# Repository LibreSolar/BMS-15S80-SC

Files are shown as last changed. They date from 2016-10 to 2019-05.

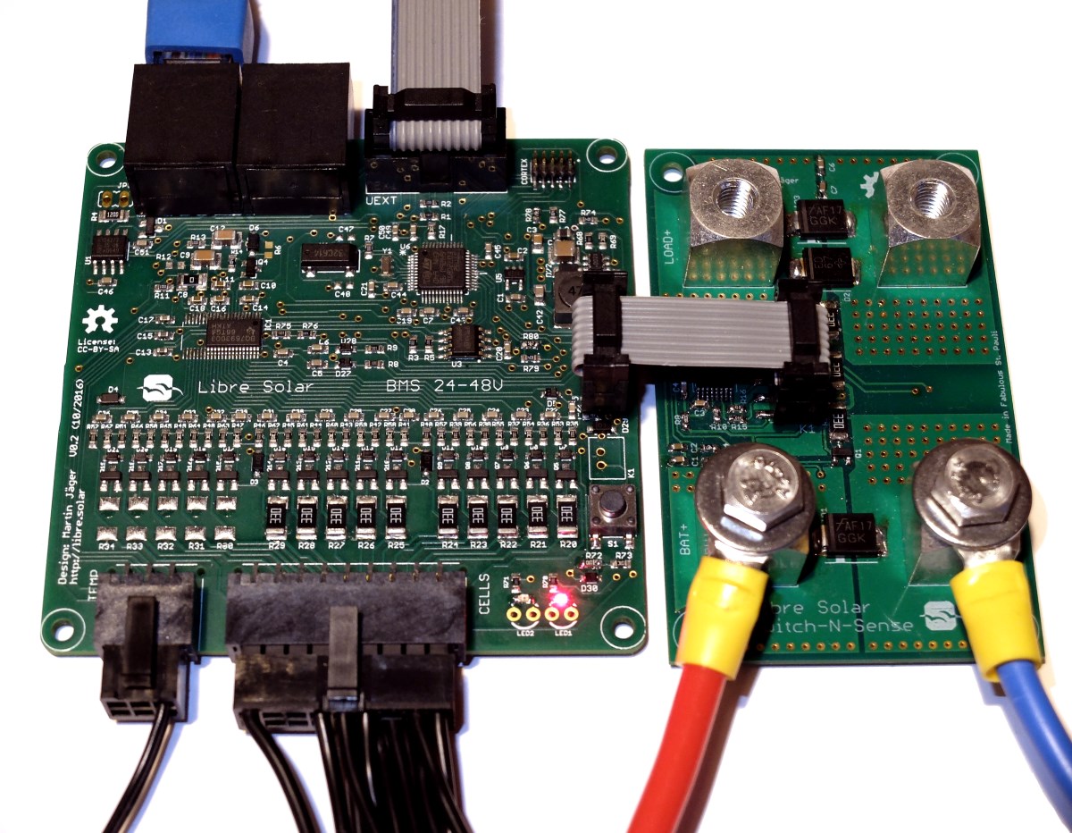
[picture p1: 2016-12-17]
doc/bms24v_board_20161217.jpg

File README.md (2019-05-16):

# BMS48V
Battery management system for up to 15 Li-ion cells based on bq76940 or bq76930 IC from Texas Instruments

Please find a good description about system integration of the BMS in the [Open Source Ecology Wiki](https://wiki.opensourceecology.de/24-48V_BMS) (in German).

## Features (updated version 10/2016):

- Up to 15 Li-ion cells (e.g. LiFePO4)
- Power circuit on separate board (see Switch-N-Sense repository)
- Balancing current approx. 150 mA
- STM32F072 ARM Cortex M0 microcontroller
- Built-in CAN communication interface and UEXT extension connector

## History

- Previous version was compatible to Arduino (based on ATmega 328P), but the processor was too small and didn't support CAN --> switched to STM32F072

(you can still find the old version by going back in the repository)

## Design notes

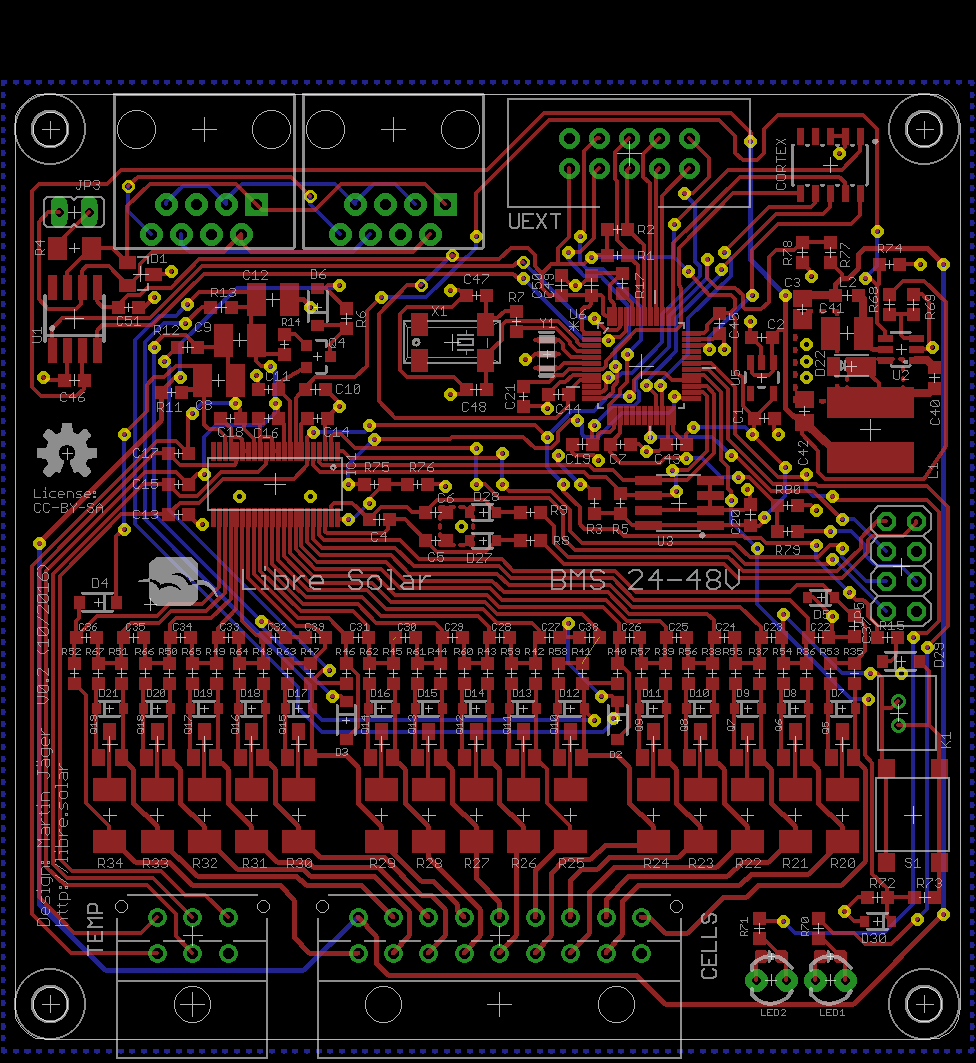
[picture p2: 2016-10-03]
LibreSolar_BMS48V_board.png

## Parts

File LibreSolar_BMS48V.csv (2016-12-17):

Qty | Value | Device | Package | Parts | Description | MF | MPN | OC_FARNELL | OC_NEWARK | PACKAGE | PROD_ID | SUPPLIER | VALUE
1 |  | 430182050816 | 430182050816 | S1 | 6x6 mm SMD WS-TASV
1 |  | 66201821022 | 66201821022 | CELLS | WR-MPC3 3.00mm Male Dual Row Angled Header with Plastic Pegs, 18 Pins=>Code : Con_WTB-MPC3_2_PCB_THT66201821022
1 |  | JP1Q | JP1 | JP3 | JUMPER
2 |  | LED0603 | LED-0603 | D24, D26 | LEDs |  |  | unknown
2 |  | LED3MM | LED3MM | LED1, LED2 | LEDs |  |  | unknown
1 |  | PINHD-2X4 | 2X04 | JP5 | PIN HEADER
1 | 0R | R-EU_R0603 | R0603 | R7 | RESISTOR, European symbol | YAGEO (PHYCOMP) | RC0603FR-0710KL | 9238603
3 | 100 | R-EU_R0603 | R0603 | R11, R12, R13 | RESISTOR, European symbol | MULTICOMP | MCMR06X1001FTL | 2073348
1 | 100k | R-EU_R0603 | R0603 | R14 | RESISTOR, European symbol |  |  | unknown
3 | 100k | R-EU_R0603 | R0603 | R72, R77, R79 | RESISTOR, European symbol | MULTICOMP | MCMR06X1001FTL | 2073348
1 | 100k | R-EU_R0603 | R0603 | R74 | RESISTOR, European symbol | PANASONIC ELECTRONIC COMPONENTS | ERJ3EKF1002V | 2303192
2 | 100n | C-EUC0603 | C0603 | C46, C51 | CAPACITOR, European symbol | AVX | 06035C104KAT2A | 1301804
6 | 100n | C-EUC0603 | C0603 | C20, C21, C43, C44, C45, C49 | CAPACITOR, European symbol | MURATA | GRM188R71H104KA93D | 8820023
24 | 100n | C-EUC0603 | C0603 | C4, C5, C6, C7, C19, C22, C23, C24, C25, C26, C27, C28, C29, C30, C31, C32, C33, C34, C35, C36, C37, C38, C39, C40 | CAPACITOR, European symbol | WALSIN | 0603B104K500CT | 2496834
1 | 10k | R-EU_R0603 | R0603 | R73 | RESISTOR, European symbol | MULTICOMP | MCMR06X1001FTL | 2073348
16 | 10k | R-EU_R0603 | R0603 | R53, R54, R55, R56, R57, R58, R59, R60, R61, R62, R63, R64, R65, R66, R67, R69 | RESISTOR, European symbol | PANASONIC ELECTRONIC COMPONENTS | ERJ3EKF1002V | 2303192
1 | 10k | R-EU_R0603 | R0603 | R17 | RESISTOR, European symbol | YAGEO (PHYCOMP) | RC0603FR-0710KL | 9238603
3 | 10µ | C-EUC1210 | C1210 | C8, C9, C12 | CAPACITOR, European symbol | MURATA | GRM32ER7YA106KA12L | 1735537
2 | 12.5p | C-EUC0603 | C0603 | C47, C48 | CAPACITOR, European symbol | MURATA | GRM188R71H104KA93D | 8820023
1 | 120 | R-EU_R1206 | R1206 | R4 | RESISTOR, European symbol | WELWYN | WCR0805-120RFI | 1100308
1 | 1M | R-EU_R0603 | R0603 | R76 | RESISTOR, European symbol | PANASONIC ELECTRONIC COMPONENTS | ERJU06F1004V | 2145441
5 | 1N4148W | DIODESOD123 | SOD-123 | D2, D3, D4, D6, D29 | Diode | DIODES INC. | 1N4148W-7-F. | 1776392
21 | 1k | R-EU_R0603 | R0603 | R8, R9, R35, R36, R37, R38, R39, R40, R41, R42, R43, R44, R45, R46, R47, R48, R49, R50, R51, R52, R75 | RESISTOR, European symbol | MULTICOMP | MCMR06X1001FTL | 2073348
1 | 1µ | C-EUC0603 | C0603 | C10 | CAPACITOR, European symbol | AVX | 0805YC475KAT2A | 1657937
1 | 1µ | C-EUC0603 | C0603 | C2 | CAPACITOR, European symbol | AVX | 08055C104KAT2A | 499687
4 | 1µ | C-EUC0603 | C0603 | C11, C14, C16, C18 | CAPACITOR, European symbol | MURATA | GRM188R71E105KA12D | 1735540
1 | 1µ | C-EUC0805 | C0805 | C3 | CAPACITOR, European symbol | AVX | 08055C104KAT2A | 499687
4 | 2.2k | R-EU_R0603 | R0603 | R1, R2, R3, R5 | RESISTOR, European symbol | YAGEO (PHYCOMP) | RC0603FR-072K2L. | 9238522
2 | 2.2µ | C-EUC0603 | C0603 | C1, C50 | CAPACITOR, European symbol | AVX | 0805YC475KAT2A | 1657937
1 | 2.2µ | C-EUC1210 | C1210 | C41 | CAPACITOR, European symbol | TDK | C3225X7R2A225K230AB | 2112727
1 | 22µ | C-EUC0805 | C0805 | C42 | CAPACITOR, European symbol | MURATA | GRM21BR60J226ME39L | 1735531
4 | 3.3V | DIODE-ZENER5.6V | SOD-323 | D5, D27, D28, D30 | Zener Diode | NXP | BZX384-C5V6 | 8735743 |  |  | DIO-12442 |  | 5.6V
15 | 33 | R-EU_R2010 | R2010 | R20, R21, R22, R23, R24, R25, R26, R27, R28, R29, R30, R31, R32, R33, R34 | RESISTOR, European symbol | WELWYN | ASC2010-33RFT4 | 2079038
2 | 330 | R-EU_R0603 | R0603 | R70, R71 | RESISTOR, European symbol | MULTICOMP | MCMR06X1001FTL | 2073348
3 | 4.7n | C-EUC0603 | C0603 | C13, C15, C17 | CAPACITOR, European symbol | WALSIN | 0603B104K500CT | 2496834
1 | 4.7uH | L-EUL2012C | L2012C | L2 | INDUCTOR, European symbol
1 | 47uH | WE-TPC_6823 | WE-TPC_6823 | L1 | Shielded Tiny Power Inductor WE-TPC
15 | 5.6V | DIODE-ZENER5.6V | SOD-323 | D7, D8, D9, D10, D11, D12, D13, D14, D15, D16, D17, D18, D19, D20, D21 | Zener Diode | NXP | BZX384-C5V6 | 8735743 |  |  | DIO-12442 |  | 5.6V
3 | 5.6k | R-EU_R0603 | R0603 | R15, R78, R80 | RESISTOR, European symbol | MULTICOMP | MCMR06X1001FTL | 2073348
1 | 56k | R-EU_R0603 | R0603 | R68 | RESISTOR, European symbol | BOURNS | CR0805-FX-1001ELF | 2008380
1 | 62000211622 | 62000211622 | 62000211622 | K1 | WR-WTB 2.00mm Male Vertical Shrouded Header, 2 Pins=>Code : Con_WTB_2.00_PCB_THT_62000211622
1 | 66200621022 | 66200621022 | 66200621022 | TEMP | WR-MPC3 3.00mm Male Dual Row Angled Header with Plastic Pegs, 6 Pins=>Code : Con_WTB-MPC3_2_PCB_THT66200621022
1 | 66200621122 | 66200621122 | 66200621122 | K4 | WR-MPC3 3.00mm Male Dual Row Vertical Header, 6 Pins=>Code : Con_WTB_MPC3_2_PCB_THT_66200621122
1 | 66201821122 | 66201821122 | 66201821122 | K5 | WR-MPC3 3.00mm Male Dual Row Vertical Header, 18 Pins=>Code : Con_WTB_MPC3_2_PCB_THT_66201821122
1 | 8MHz | RESONATOR1:1 | RESONATOR-SMD-1:1 | Y1 | Resonator | MURATA | CSTCE8M00G55-R0 | 2443270
1 | ABS25-32.768KHZ-T | CRYSTALMM20SS | MM20SS | X1 | CRYSTAL |  |  | unknown | unknown
1 | BQ76940 | BQ76940 | TSSOP44 | IC1 |  | TEXAS INSTRUMENTS | BQ7694003DBT | 2425791
1 | BSS123 | MOSFET-NCHANNELBSS138 | SOT23-3 | Q4 | Common NMOSFET Parts | NXP | 2N7002,215 | 1510761 |  |  | TRANS-00830 |  | 200mA/50V
1 | CORTEX_DEBUGSMD | CORTEX_DEBUGSMD | SAMTECH_FTSH-105-01 | CORTEX | Cortex Debug Connector
1 | DFLS1100-7 | SCHOTTKY-DIODEPOWERDI123 | POWERDI123 | D22 | Schottky Diode | DIODES INC. | DFLS1100-7 | 1713889
15 | DMN2004K | DMN2004K | SOT23 | Q5, Q6, Q7, Q8, Q9, Q10, Q11, Q12, Q13, Q14, Q15, Q16, Q17, Q18, Q19 | N-CHANNEL MOS FET with low VGS and ESD protection | DIODES INC. | DMN2004K-7 | 1713842
1 | LIBRESOLAR_LOGO | LIBRESOLAR_LOGO | LIBRESOLAR_LOGO | U$1
1 | LMR16006X | LMR16006SOT-23 | SOT23-6 | U2 | LMR16006 SIMPLE SWITCHER® 60 V 0.6 A Buck Regulators With High Efficiency ECO Mode | TEXAS INSTRUMENTS | LMR16006XDDCT | 2455133 |  |  |  |  | LMR16006
1 | M24256-BW | EEPROM-I2CSMD | SO08 | U3 | I2C EEPROM chips, 24LC256 (and others)
1 | MIC5225 | V_REG_MIC5235 | SOT23-5 | U5 |  | MICROCHIP | MIC5225-3.3YM5-TR | 2510262
4 | MOUNT-HOLE2.8 | MOUNT-HOLE2.8 | 2,8 | H1, H2, H3, H4 | MOUNTING HOLE with drill center marker |  |  | unknown
1 | OSHW-LOGOM | OSHW-LOGOM | OSHW-LOGO-M | N1 | Open Source Hardware Logo This logo indicates the piece of hardware it is found on incorporates a OSHW license and/or adheres to the definition of open source hardware found here: http://freedomdefined.org/OSHW |  |  | unknown
1 | PESD2CAN | PESD2CAN | SOT23 | D1 | CAN bus ESD protection diode | NXP | PESD2CAN | 1510712
2 | RJ45 | RJ45-8PTH | RJ45-8 | JP1, JP2 | RJ45 Jack | AMPHENOL COMMERCIAL PRODUCTS | RJHSE-5080 | 1860577 |  |  | CONN-08506 |  | RJ45
1 | STM32F072CB | STM32F072CB | QFP50P900X900X160-48N | U6 | ARM-based 32-bit MCU |  | STM32F100C4T6B | 1838504 | 86R1309 | LQFP-48 |  | STMircroelectronics
1 | TJA1042T/3 | TJA1042T/3 | SOIC-8-N | U1 | 3.3V CAN transceiver
1 | UEXT | UEXT | UEXT | UEXT | WR-BHD 2.54mm Male Box Header, 10 Pins=>Code : Con_WTB_BHD_2.54_Male_THT_WS_61201021621
1 | t.b.d. | R-EU_R0603 | R0603 | R6 | RESISTOR, European symbol | MULTICOMP | MCMR06X1001FTL | 2073348

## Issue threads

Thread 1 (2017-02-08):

More than 10 cells for 24V Batterypack

mulles, 2017-02-08:
Hi,

I am currently planning to build a 24V Batterypack with 16 Headway LifePO4 40152S 15Ah Cells. Which I would need 8 in Serie for 24V and would like to have 2x8Series in parallel for a 16Cell total. The goal is to power my room with 220Wp Solarpanel on 24Volt.

I like your project and I hope and some point you can ship the solarcharger and BMS to interested people.

My feature request would be to support more than 10cells, if that not the case yet, so that me and other can use the BMS in future.

Keep up the incredible work!

edit: I misunderstood some basics. I am all good with the 10 cells possibility :)

Closed 2017-02-08.

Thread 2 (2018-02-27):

CAN transceiver not working

martinjaeger, 2018-02-27:
The CAN_STB pin is not wired because of naming mismatch, so the CAN transceiver cannot be switched on. Workaround: Hard-wire it to GND.

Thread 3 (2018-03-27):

Specification

happytm, 2018-03-27:
What are the specifications for this board? specially compared to [http://electrodacus.com/SBMS100/manual/SBMSmanual.pdf](url)

martinjaeger, 2018-03-27:
Compared to the SBMS, this one has a more modular approach. The control PCB and the power PCB (Switch'N'Sense) are separated and it is not targeted only for solar applications. In addition to that, it can handle higher voltages and cell numbrrs.

happytm, 2018-03-27:
Thank you very much.

Closed 2018-03-27.

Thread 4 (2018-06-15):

Cell voltage measurement at group boundary influenced by balancing of adjacent cell

frankrichter, 2018-06-15:
The cell voltage measurements of cell 5 and 6 (also cell 10 and 11 with bq76940) are influenced by the balancing current of the adjacent cell in the other cell group.
The voltage deviation depends on the resistance between BMS and cell, in my case it was about 15-20mV. With this error the BMS can't achieve an accurate balancing.
This happens because the clocks of the 2 or 3 cell groups are not synchronized.

From "bq769x0 Family Top 10 Design Considerations" (SLUA749A) chapter 4 p. 9:
> The timelines of the cell groups in the bq76930 and bq76940 are independent, so one group may be balancing while the next group is measuring. At the cell boundary between groups, the adjacent cell may measure a voltage from the balance current in any common path. Keeping the common path resistance low, using wide traces or returning the current as close to the cell as possible will reduce this effect (see Figure 8).

Working solution/workaround: Remove the connections between VC5/VC5B and VC10/VC10B on the board and connect them to the respective cell with separate wires. Therefore the cells connector should be changed to a 20 pin model.
With 10s version it is possible to use one of the spare pins C11-C15 (see attached photos of my hacked board):
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

SolarDude, 2019-01-20:
frankrichter Nice catch!

So does your workaround as pictured also prevent this issue on Cell 10 & 11?

frankrichter, 2019-01-20:
No, if you use the 15 cell version, you also have to split the C10
connection. And you can't use any spare pins in this case either.

We are currently working on a pull request which adresses this issue by
replacing the cells connector with a 20 pin model.

Am So., 20. Jan. 2019, 05:12 hat SolarDude <notifications@github.com>
geschrieben:

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

SolarDude, 2019-01-20:
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

I want to make the changes on my board so the cell voltage is as accurate as possible.

The BQ76940 EVM is only using 16 cell input pins so are you saying that this issue voltage drop during balancing issue may be happening on the EVM module also? Or maybe not as noticeable because the EVM board is not setup with resistors to balance at 150mA which would cause a less of a voltage drop?

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

I think maybe the smaller traces running to the balancing resistors & circuit could also be adding to the voltage drop during balancing. You can see how wide the traces are that run to the balancing resistors on their EVM boards.

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

It seems like if we want to keep the board small and not increase the width of the traces running from the 18 or a new 20 pin connector to the balancing resistors then running a extra voltage sense wire to VC5B & VC10B pins would provide the most accurate cell voltage readings and balancing performance.

Took me awhile to wrap my head around what your workaround but now I understand what is going on.

I'm going to make these changes today. I've imported the Eagle project to KiCad 5.0.2-1 and that went well except for most of the Global Labels were just text so I have to change all those to proper Global Labels and the part text indicators needed moved around so they were not directly under some parts.

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

I'm adding the bq78350 chip to the mix the same as the EVM modules and I'm using the Particle Photon Wifi MCU since I'm used to using that module.

Do you see any reason this 48v board would not be usable with either the BQ76920, BQ76930, or BQ76940 AFE chips? It would be nice for one board to be able to handle 4, 8, 15 cell LiFePo4 battery Packs.

martinjaeger, 2019-01-20:
Very nice that you are transferring the board to KiCad. We could open a separate branch of the Particle Photon version or open a new repository, if you like.

Unfortunately, the bq76920 has a different pin pitch than the other two, so this this board currently supports only the 30 and 40 chips. I'm using it with the bq76930 and 8 cells.
The [TI top 10 design considerations document](http://www.ti.com/lit/an/slua749a/slua749a.pdf) makes a suggestion for board layout to support all 3 chip types. But it doesn't allow any traces below the chip anymore.

frankrichter, 2019-01-20:
> It seems like if we want to keep the board small and not increase the width of the traces running from the 18 or a new 20 pin connector to the balancing resistors then running a extra voltage sense wire to VC5B & VC10B pins would provide the most accurate cell voltage readings and balancing performance.

Yes, even with wider traces the measurements will still be affected by the voltage drop caused by the connector and the wire between BMS and cell.
Separate sense wires will do the trick regardless of the resistance and the applied balancing current. That's why I went for this solution.

SolarDude, 2019-01-20:
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

Makes sense.

The 20 pin connector can be added pretty easily without needing to move the current temp sensor port.

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

The new last 2 pins on the left of cell port just need to be connected to VC5B & VC10B to fix the issue.

I need to change all these global labels on the KiCad conversion before I can properly draw new wires to the new pins but the change is really easy. I'll report back once I get this done.

SolarDude, 2019-01-20:
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

I wonder if making a simple adapter board with castellated edges or something similar that would allow us to keep the current TSSOP 40 footprint but allow us to put the bq76920 chip on top of the adapter board and then reflow the adapter board to the 40 pin fooprint.

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

I'm not sure if this is possible, the pitch is really small.

SolarDude, 2019-01-20:
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

Your talking about cutting where you see the Blue X marks and adding where you see the bright RED lines?

Then connect the new C5+ & C10+ connections to where you see the White C5+ and C10+ text right?

frankrichter, 2019-01-20:
Your cuts are ok, your new connections aren't. You have to connect C5/C10 to the lower pad of R40/46, not to the upper pad.
Please refer to the photo in my first post. There is no connection between the enameled copper wire and the trace below.

frankrichter, 2019-01-20:
Yes, this is how we modded our board. Since then it is working flawlessly.

Additionnally it would make sense to connect the C5 and C10 vias to C5/C10 and not to the newly created C5+/C10+ like in your image, otherwise it won't work if you connect only 10 cells and leave out the C10+ connection which is not necessary for 10 cells.

SolarDude, 2019-01-20:
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

Great, makes sense to connect to the Vias as you did in your mod.

I think I know exactly what is going on now and can properly make the changes.

What is your battery pack setup? How much current? Which Sense board are you using?

SolarDude, 2019-01-20:
Looks like adding the footprint for the BQ76920 would not require to much modification based on what I'm seeing here:

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

I'm going attempt to add the footprint and make this a board that can handle the whole range of normal battery pack configurations.

frankrichter, 2019-01-20:
> Great, makes sense to connect to the Vias as you did in your mod.

In the mod the via is connected to C5+/C10+ like in your image. In a new layout this should be avoided.

> What is your battery pack setup?

9 of these cells: https://www.lithiumakkushop.de/product/innopower-lfmp-60ah/

> How much current?

about 30A

> Which Sense board are you using?

https://github.com/LibreSolar/Switch-N-Sense

SolarDude, 2019-01-21:
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

So just so we are clear.

You are saying the new C5+ and C10+ should connect at the vias that the orange arrows are pointing to?

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

SolarDude, 2019-01-21:
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

SolarDude, 2019-01-21:
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

What kind of heat does the sense board produce at 30 amps?

How much current testing have you done with the board? Just curious what is possible.

I have one on order with 2oz copper on both sizes of the board.

frankrichter, 2019-01-21:
I will do a quick drawing in the evening, but it's not as complicated as you think ;-)

SolarDude, 2019-01-21:
I think I got the new 20 Pin connector added and the wiring modified to prevent the cell voltage offset issue from happening. Take a look at the schematic and let me know if you see anything wrong.

I made sure I copied the new schematic you posted so we are on the same page as far as the C5 & C10 connections.

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

frankrichter, 2019-01-21:
Looks good!

photon-delight, 2020-11-11:
> Very nice that you are transferring the board to KiCad. We could open a separate branch of the Particle Photon version or open a new repository, if you like.

Just wondering whether the KiCad version ever made it into a repo?

MichiS79, 2021-02-07:
I would also like to re-build the BMS and curious if there any updates. @SolarDude Could share your the KiCad version?
Thx a lot.

utshab01, 2024-04-28:
https://batterlution.com/bms-problems-solved-fast-from-balcony-to-industrial-energy-storage/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

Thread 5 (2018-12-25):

Hot BSS123!

ArashIranfar, 2018-12-25:
Hi,
I am trying to design a BMS board based on what Texas Instruments have published as the evaluation board and what you have designed as a practical example. The problem I have is with the part you called "Source follower for decreased voltage drop in internal LDO (100V N-MOS)". The FET is getting really hot! The VC5X port of the chip is pulling the Gate up to 9 volts but the Source is somehow already at 8 volts so the Vgs is more or less 1 V and I think this is the problem because it increases the Rdson which can result in more power dissipation in the FET. I've seen some designs with a 200 Ohm resistor connected between the Source and the capacitor which may solve my issue as well but I think this may result in more power dissipation in the bq76940 itself which can't be good but that's a solution none the less.
Also, I only have a STM32F103VET6 and some 10K pull-up resistors on the board and the internal LDO is supplying 3.1 V with 37 mA right now. Is this too much?!
I've attached the schematic file to my board if you could kindly check it.

Thank you.

[EmbededSystem.zip](https://github.com/LibreSolar/BMS48V/files/2708158/EmbededSystem.zip)

martinjaeger, 2018-12-25:
It's the goal of that MOSFET to dissipate power. And it gets more the more power you consume from the internal 3V3 LDO. Did not see any issues in my design so far.

Please check the datasheet to see how much supply current the internal LDO can handle.

Can't read your schematic file format...

ArashIranfar, 2019-01-06:
Thanks. The problem as you mentioned was with the power consumption of the board. My MCU clock was set to the highest possible value (42Mhz) and it needed 36mA. The problem is solved thanks.

P.S.: The schematic file was an Altium schematics and apparently you use Eagle ... I attached the PDF of the schematics in case you would like to check it...
[Schematics-BQ76940.pdf](https://github.com/LibreSolar/BMS48V/files/2730209/Schematics-BQ76940.pdf)

Closed 2018-12-25.

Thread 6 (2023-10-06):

Which MCU model is supported?

Retro-Fitt, 2023-10-06:
Very nice project. I am designing a custom BMS based (bq76930 10s) on your work. Thank you very much for such work.

I have a couple of questions:

- Is MCU STM32F072C**B** or STM32F072C**8** series?

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

- Is STM32F072RBT6 (64 pin version) compatible with your bms firmware?

- Is CRC mandatory to commucate with MCU? CRC or without CRC which one is compatible with your bms firmware?

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

- Is LDO voltage relevant? Which is prefered?2.5 or 3.3?

- Is "rev2" branch hw design tested?

Thanks

martinjaeger, 2023-10-06:
> * Is MCU STM32F072C**B** or STM32F072C**8** series?

Definitely C**B** series with more flash memory.

> * Is STM32F072RBT6 (64 pin version) compatible with your bms firmware?

Yes, pinout doesn't really matter from firmware side.

> * Is CRC mandatory to commucate with MCU? CRC or without CRC which one is compatible with your bms firmware?

Both types with and without CRC are supported. The firmware detects automatically if CRC is required.

> * Is LDO voltage relevant? Which is prefered?2.5 or 3.3?

That's purely a hardware question. For the existing bms-15s80-sc board it must be 3.3V.

> * Is "rev2" branch hw design tested?

Yes. Not by myself, but by @thomasplaz.

For any new hardware design I would recommend to choose an MCU with more RAM and flash, which will make firmware upgrades via CAN and other things much easier. Either STM32G0 series or STM32F091.

Retro-Fitt, 2023-10-06:
Many many thanks for quick reply.

I will consider more powerfull MCU but i am not familiar with Zephyr OS.(I will study it.) Is it easy to implement another STM MCU to existing bms firmware? If so, do you have any resources (links-videos-pdf etc.) so i can educate myself on firmware?

martinjaeger, 2023-10-06:
Yes, that's one of the main advantages of Zephyr. Basically you just need to add another board specification to the `boards/` folder. If you stay within STM32 MCU lines, you can take an existing board and most probably need to change just a few lines in the devicetree.

Some links:
https://blog.golioth.io/how-to-add-a-custom-board-definition-to-a-zephyr-application/
https://docs.zephyrproject.org/latest/hardware/porting/board_porting.html

Retro-Fitt, 2023-10-09:
Many thanks for links.I will study them. I decided to use STM32F091CCT6. I will make a pull request if i will able to port this mcu to your firmware.

Another question regarding precharge mosfet  on [Switch-N-Sense](https://github.com/LibreSolar/switch-n-sense#switch-n-sense)  . In BQ76930 datasheet precharge mosfet source pin is connected to BAT+( Battery most positive terminal) as shown below:
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
Which is logical i assume.

But in switch n sense it is connected to LOAD+ side.
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

I couldn't understand why? Could you please explain?

martinjaeger, 2023-10-09:
The path is to precharge the bus, not the battery. This is sometimes also called pre-discharge.

See also here: https://learn.libre.solar/system/bms.html#bus-precharge

Retro-Fitt, 2023-10-25:
Hi again
I completed my hardware design, bought parts for it and ordered PCB.

**************
**_For those people are reading this on future and considering building a custom BMS:_**
In my hardware design i combined **bms-15s80** with **switch and sense** and made a prototype for lower power requirements. (Normal operation 15A, Short Circuit operation 30A, Overcurrent operation 20A) I didn't finalized it yet it's just prototype to test things out and how they fit to real world. My power need is about 250W in total. I didn't decided cell counts yet and put some solder jumpers on PCB.
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
Cost of 5 PCB is about 2 USD without shipping. I included LCSC part numbers on my schematic to order parts easily. All parts cost 10.44 USD as date without shipping per board so in total 10.84 USD which seems very reasonable for such capable BMS of course you have to assemble parts by hand and shipping costs should be considired. The board has 2 layers with two power mosfet's. I will test hardware and may fork from martin's original work. Here is BOM file "for all those playing at home":
[bom.csv](https://github.com/LibreSolar/bms-15s80-sc/files/13164212/bom.csv)

****************

While waiting to shipping and PCB manufacturing process i decided to exercise with porting bms firmware, read many documents related to porting thanks for links, many things to learn.
I actually decided to use STM32F091CCT6 (256KB FLASH and 32KB RAM) instead of STM32F072RBT6 (128KB FLASH and 16KB RAM) but due to no stock available on LCSC i had to buy F072RBT6 for testing. I compiled original firmware without any errors.
```
$ west build -b bms_15s80_sc@v23.0-brach --pristine
.....
.....
.....
[175/175] Linking CXX executable zephyr/zephyr.elf
Memory region         Used Size  Region Size  %age Used
           FLASH:      103732 B       128 KB     79.14%
            SRAM:       14280 B        16 KB     87.16%
        IDT_LIST:          0 GB         2 KB      0.00%
```
As you suggested RAM and FLASH usages are high.

As i said before i wanted to test firmware on STM and try to learn porting it thats when i got some problems.

```
$ west flash
-- west flash: rebuilding
ninja: no work to do.
-- west flash: using runner openocd
-- runners.openocd: Flashing file: /home/jigsaw/west-workspace/bms-firmware/app/build/zephyr/zephyr.hex
Open On-Chip Debugger 0.11.0+dev-00726-ge2b6f5655 (2023-09-22-14:29)
Licensed under GNU GPL v2
For bug reports, read
	http://openocd.org/doc/doxygen/bugs.html
Info : The selected transport took over low-level target control. The results might differ compared to plain JTAG/SWD
Info : clock speed 1000 kHz
Info : STLINK V2J29S7 (API v2) VID:PID 0483:3748
Info : Target voltage: 3.150968
Warn : UNEXPECTED idcode: 0x2ba01477
Error: expected 1 of 1: 0x0bb11477
```

My ST-LINKv2 was not cooperating with me because it's a clone. 🤕 I had to change stlink.cfg in Zephyr-sdk and add " set CPUTAPID 0x2ba01477" line on it to fix it. It fixed my problem. This file is located on "zephyr-sdk-0.16.3/sysroots/x86_64-pokysdk-linux/usr/share/openocd/scripts/interface/stlink.cfg"

Then Cpu not halted problem.

```
$ west flash
-- west flash: rebuilding
ninja: no work to do.
-- west flash: using runner openocd
-- runners.openocd: Flashing file: /home/jigsaw/west-workspace/bms-firmware/app/build/zephyr/zephyr.hex
Open On-Chip Debugger 0.11.0+dev-00726-ge2b6f5655 (2023-09-22-14:29)
Licensed under GNU GPL v2
For bug reports, read
	http://openocd.org/doc/doxygen/bugs.html
Info : The selected transport took over low-level target control. The results might differ compared to plain JTAG/SWD
Info : clock speed 2000 kHz
Info : STLINK V2J29S7 (API v2) VID:PID 0483:3748
Info : Target voltage: 3.143226
Info : [stm32f4x.cpu] Cortex-M4 r0p1 processor detected
Info : [stm32f4x.cpu] target has 6 breakpoints, 4 watchpoints
Info : starting gdb server for stm32f4x.cpu on 3333
Info : Listening on port 3333 for gdb connections
    TargetName         Type       Endian TapName            State
--  ------------------ ---------- ------ ------------------ ------------
 0* stm32f4x.cpu       hla_target little stm32f4x.cpu       running

Info : Unable to match requested speed 2000 kHz, using 1800 kHz
Info : Unable to match requested speed 2000 kHz, using 1800 kHz
Error: timed out while waiting for target halted
TARGET: stm32f4x.cpu - Not halted
```

I fixed it by editing openocd.cfg file to "reset_config srst_only" to "reset_config none". This file is located on "west-workspace/bms-firmware/boards/arm/'yourboard'/support/openocd.cfg"

```
$ west flash
-- west flash: rebuilding
ninja: no work to do.
-- west flash: using runner openocd
-- runners.openocd: Flashing file: /home/jigsaw/west-workspace/bms-firmware/app/build/zephyr/zephyr.hex
Open On-Chip Debugger 0.11.0+dev-00726-ge2b6f5655 (2023-09-22-14:29)
Licensed under GNU GPL v2
For bug reports, read
	http://openocd.org/doc/doxygen/bugs.html
Info : The selected transport took over low-level target control. The results might differ compared to plain JTAG/SWD
Info : clock speed 2000 kHz
Info : STLINK V2J29S7 (API v2) VID:PID 0483:3748
Info : Target voltage: 3.143226
Info : [stm32f4x.cpu] Cortex-M4 r0p1 processor detected
Info : [stm32f4x.cpu] target has 6 breakpoints, 4 watchpoints
Info : starting gdb server for stm32f4x.cpu on 3333
Info : Listening on port 3333 for gdb connections
    TargetName         Type       Endian TapName            State
--  ------------------ ---------- ------ ------------------ ------------
 0* stm32f4x.cpu       hla_target little stm32f4x.cpu       running
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
thomasplaz, 2023-11-22:
Hi Retro Fitt,
Frank Richter and me used Martin Jäger's BMS to build a solar storage unit with a 9-cell battery and another solar storage unit with 15 cells. You can find the whole project (so far only in German at):
https://wiki.opensourceecology.de/Solarspeicher_(station%C3%A4r))

You can find the detailed instructions for building the BMS at
https://wiki.opensourceecology.de/24-48V_BMS

Maybe you can translate the pages using google translate.

After setting up the hardware of the BMS, we found the following issues:

• Connection of the CAN microcontroller pin “CAN_STB” on the BQ76940 is faulty

• The connection of cells 5/6 and 10/11 is wired in such a way that a voltage measurement with mutual interaction takes place

For our 15 cell battery, we have put an updated hardware (first) variant on github, which works in our setup.
https://github.com/LibreSolar/bms-15s80-sc/tree/rev2

The BMS board also has additional mounting holes. The cell voltage measurement works without any problems with the changed layout.

We do NOT use the SNS board and have integrated the power electronics onto our main board, which was specially designed for the storage:
https://gitlab.opensourceecology.de/soldorado-open-solar-system/solar-storage-controller-hardware
This is because we have had bad experiences in an operating state where, for example, the Mosfet discharge is closed, but the Mosfet Charge is still open.
The reverse current via the body diode and the resulting heat flow backwards through a closed Mosfet leads to the burning out of the Mosfets. Maximal currents in our arrangement go’s up to 35A.

In a second variant, the BMS board and the SNS board are combined on one board in Eagle. These files are linked at
https://wiki.opensourceecology.de/24-48V_BMS “Variant 2”.

We use mbed-based software for programming the bq769x0 because it was well suited to our purposes and we were reluctant to switch to Zephir (due to time constraints). We have now adjusted the software so that the SOC is also calculated correctly. Can be found at:
https://gitlab.opensourceecology.de/soldorado-open-solar-system/bms_software_prototyp3 and
https://gitlab.opensourceecology.de/soldorado-open-solar-system/bq769x0_mbed_lib

The new SOC calculation is not online yet, coming soon, if you need it immediately please let me know..
I hope I have given you an overview of what we have done and is maybe useful for you. If you have any questions please just ask.

Retro-Fitt, 2024-01-30:
@martinjaeger
@thomasplaz
Many thanks both of you for reply. Sorry to write late. I had some health issues, than life was busy...
Anyway i figured out that precharge mosfet source and drain pins are reversed in my schematic. I temporary soldered mosfet pins manually. Now precharge issue is fixed.

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

> As a general remark: Please feel free to open separate issues for separate things. It will help to maintain the overview. And some of the issues above are clearly related to firmware and not the board hardware, so they would ideally be discussed in the firmware repo.

I no longer have any hardware issues but i might have software issues which i will make new issue on firmware repo.

Closed 2024-01-31.

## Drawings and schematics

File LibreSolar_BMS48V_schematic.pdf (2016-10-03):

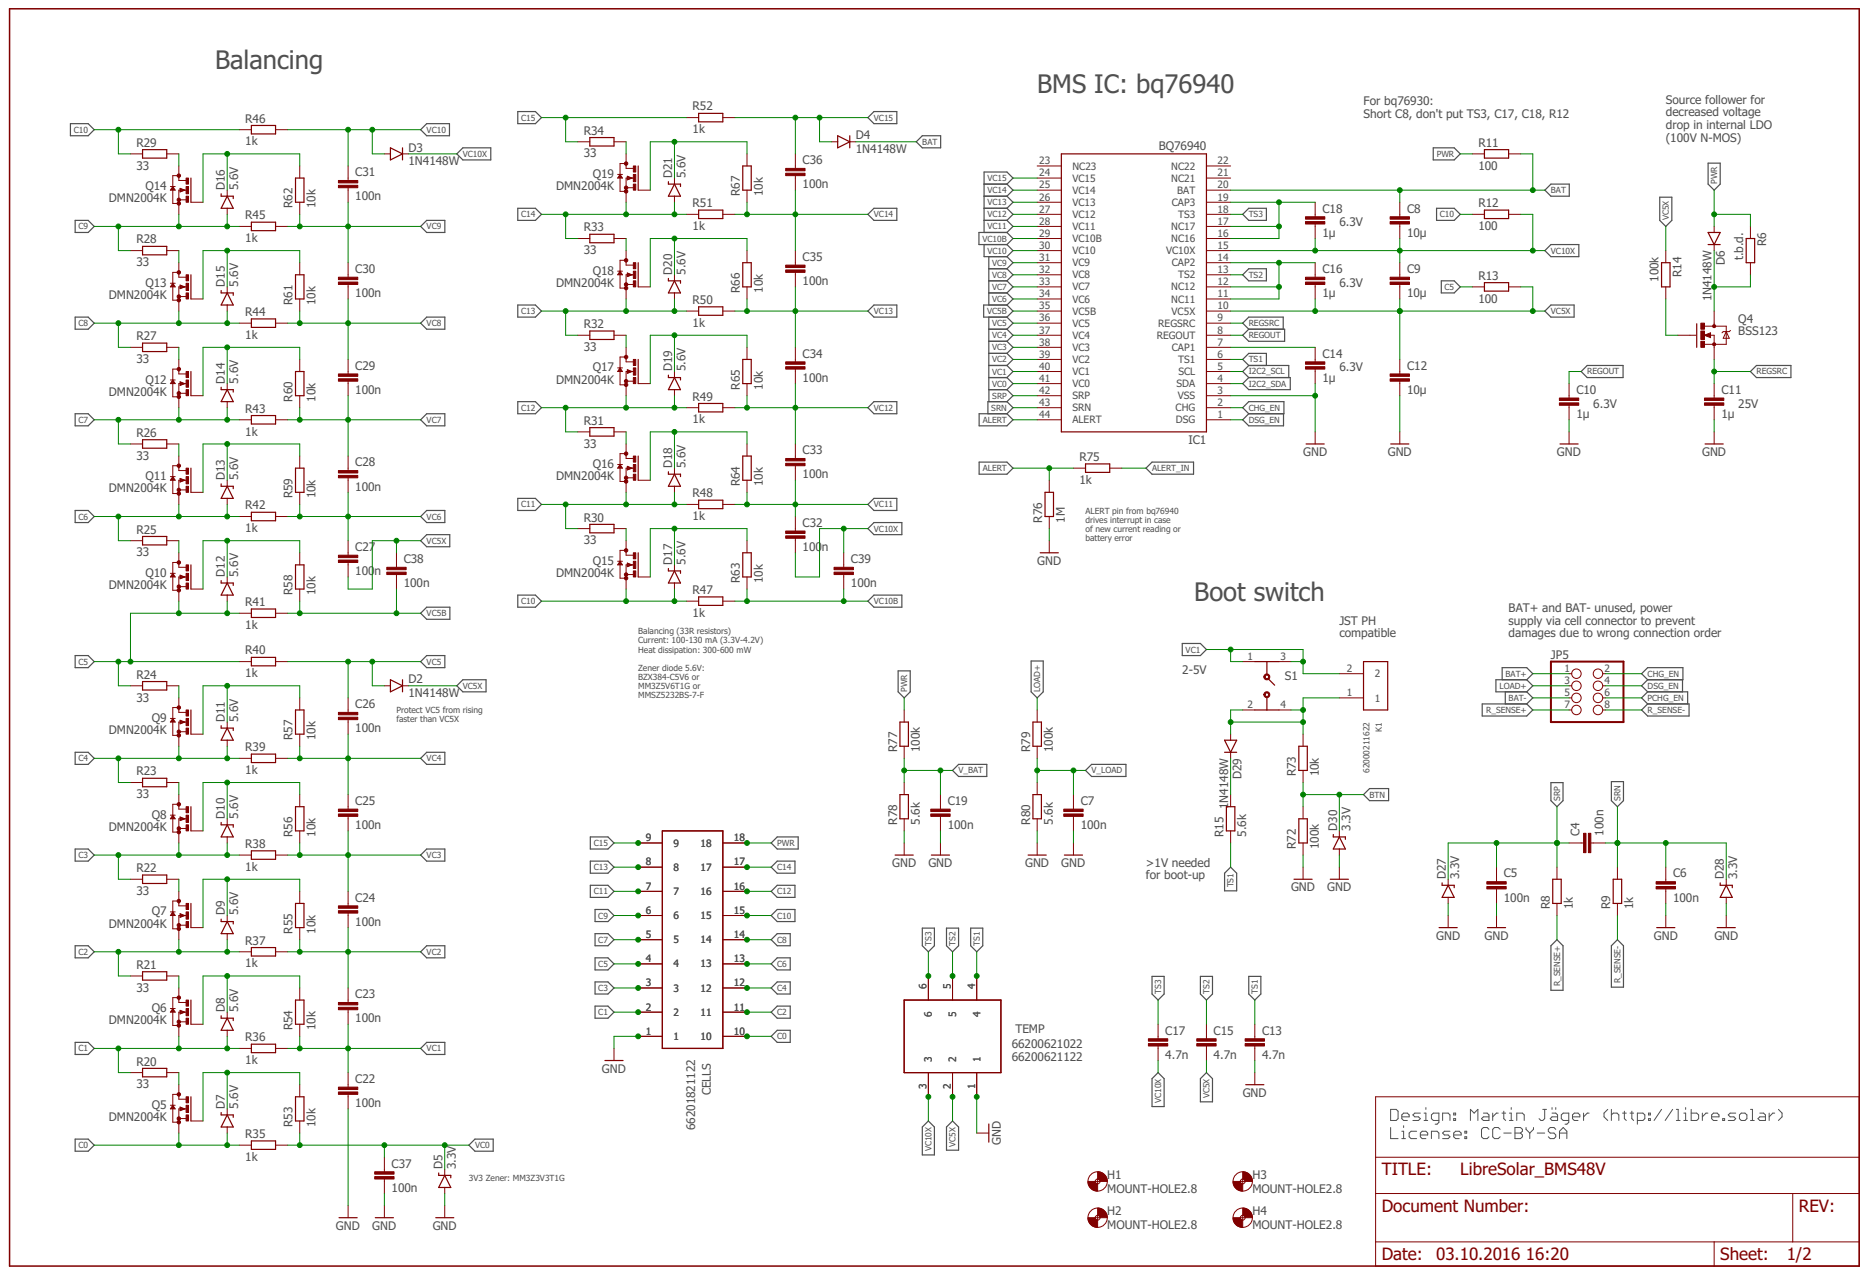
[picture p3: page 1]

For bq76930: Short C8, don't put TS3, C17, C18, R12

Source follower for decreased voltage drop in internal LDO

9 VC5X 8 REGSRC 7 REGOUT

6 CAP1 4 SCL 5 TS1 3 SDA

2 VSS 1 CHG

ALERT pin from bq76940 drives interrupt in case of new current reading or battery error

damages due to wrong connection order Boot switch

BAT+ and BAT- unused, power supply via cell connector to prevent

Balancing (33R resistors) Current: 100-130 mA (3.3V-4.2V) Heat dissipation: 300-600 mW

Zener diode 5.6V: BZX384-C5V6 or MM3Z5V6T1G or MMSZ5232BS-7-F

Document Number: | REV:

Date: 03.10.2016 16:20 | Sheet: 1/2

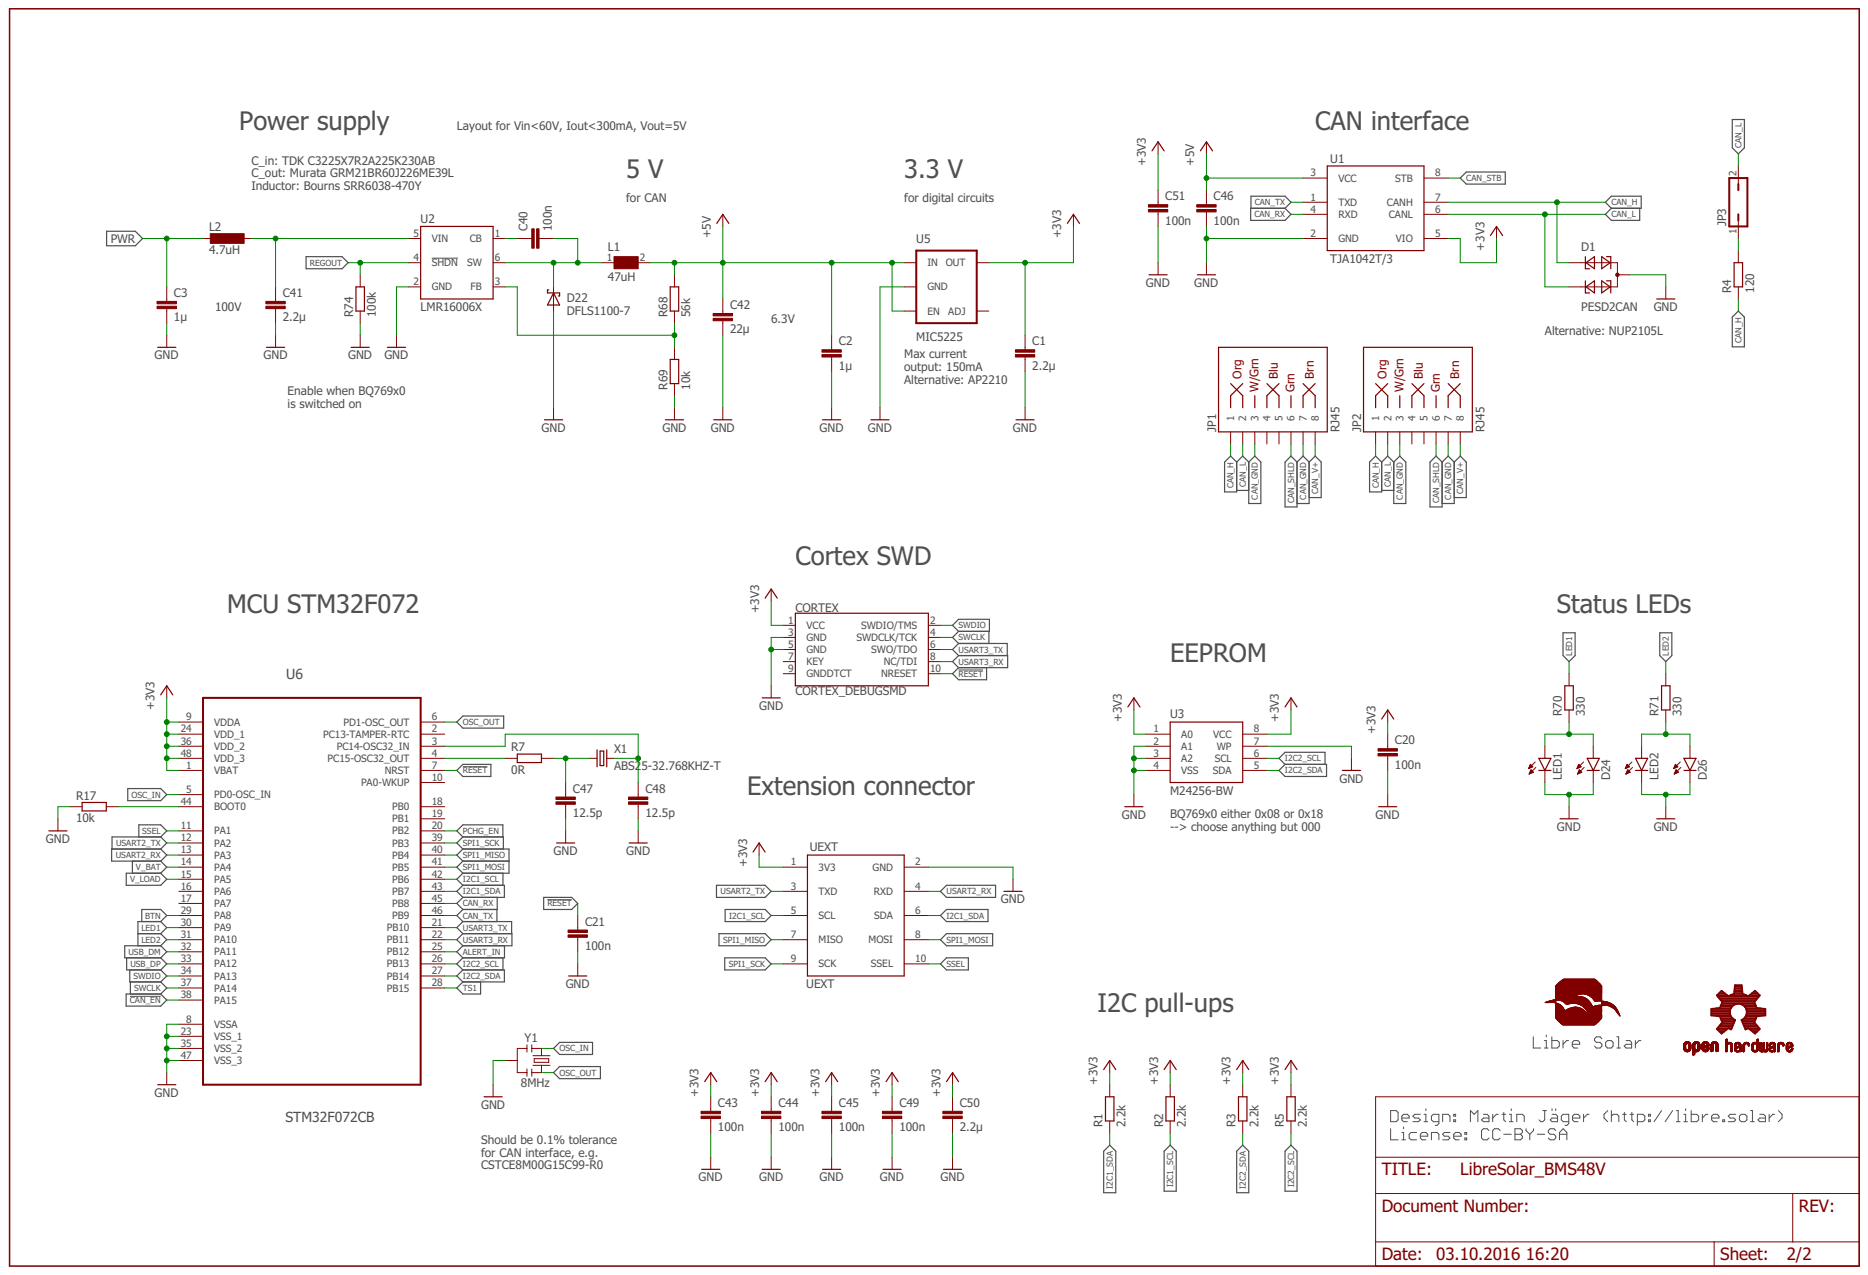
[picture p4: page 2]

Layout for Vin<60V, Iout<300mA, Vout=5V

Org Blu Brn W/Grn GrnOrg Blu Brn W/Grn Grn

Document Number: | REV:

Date: 03.10.2016 16:20 | Sheet: 2/2

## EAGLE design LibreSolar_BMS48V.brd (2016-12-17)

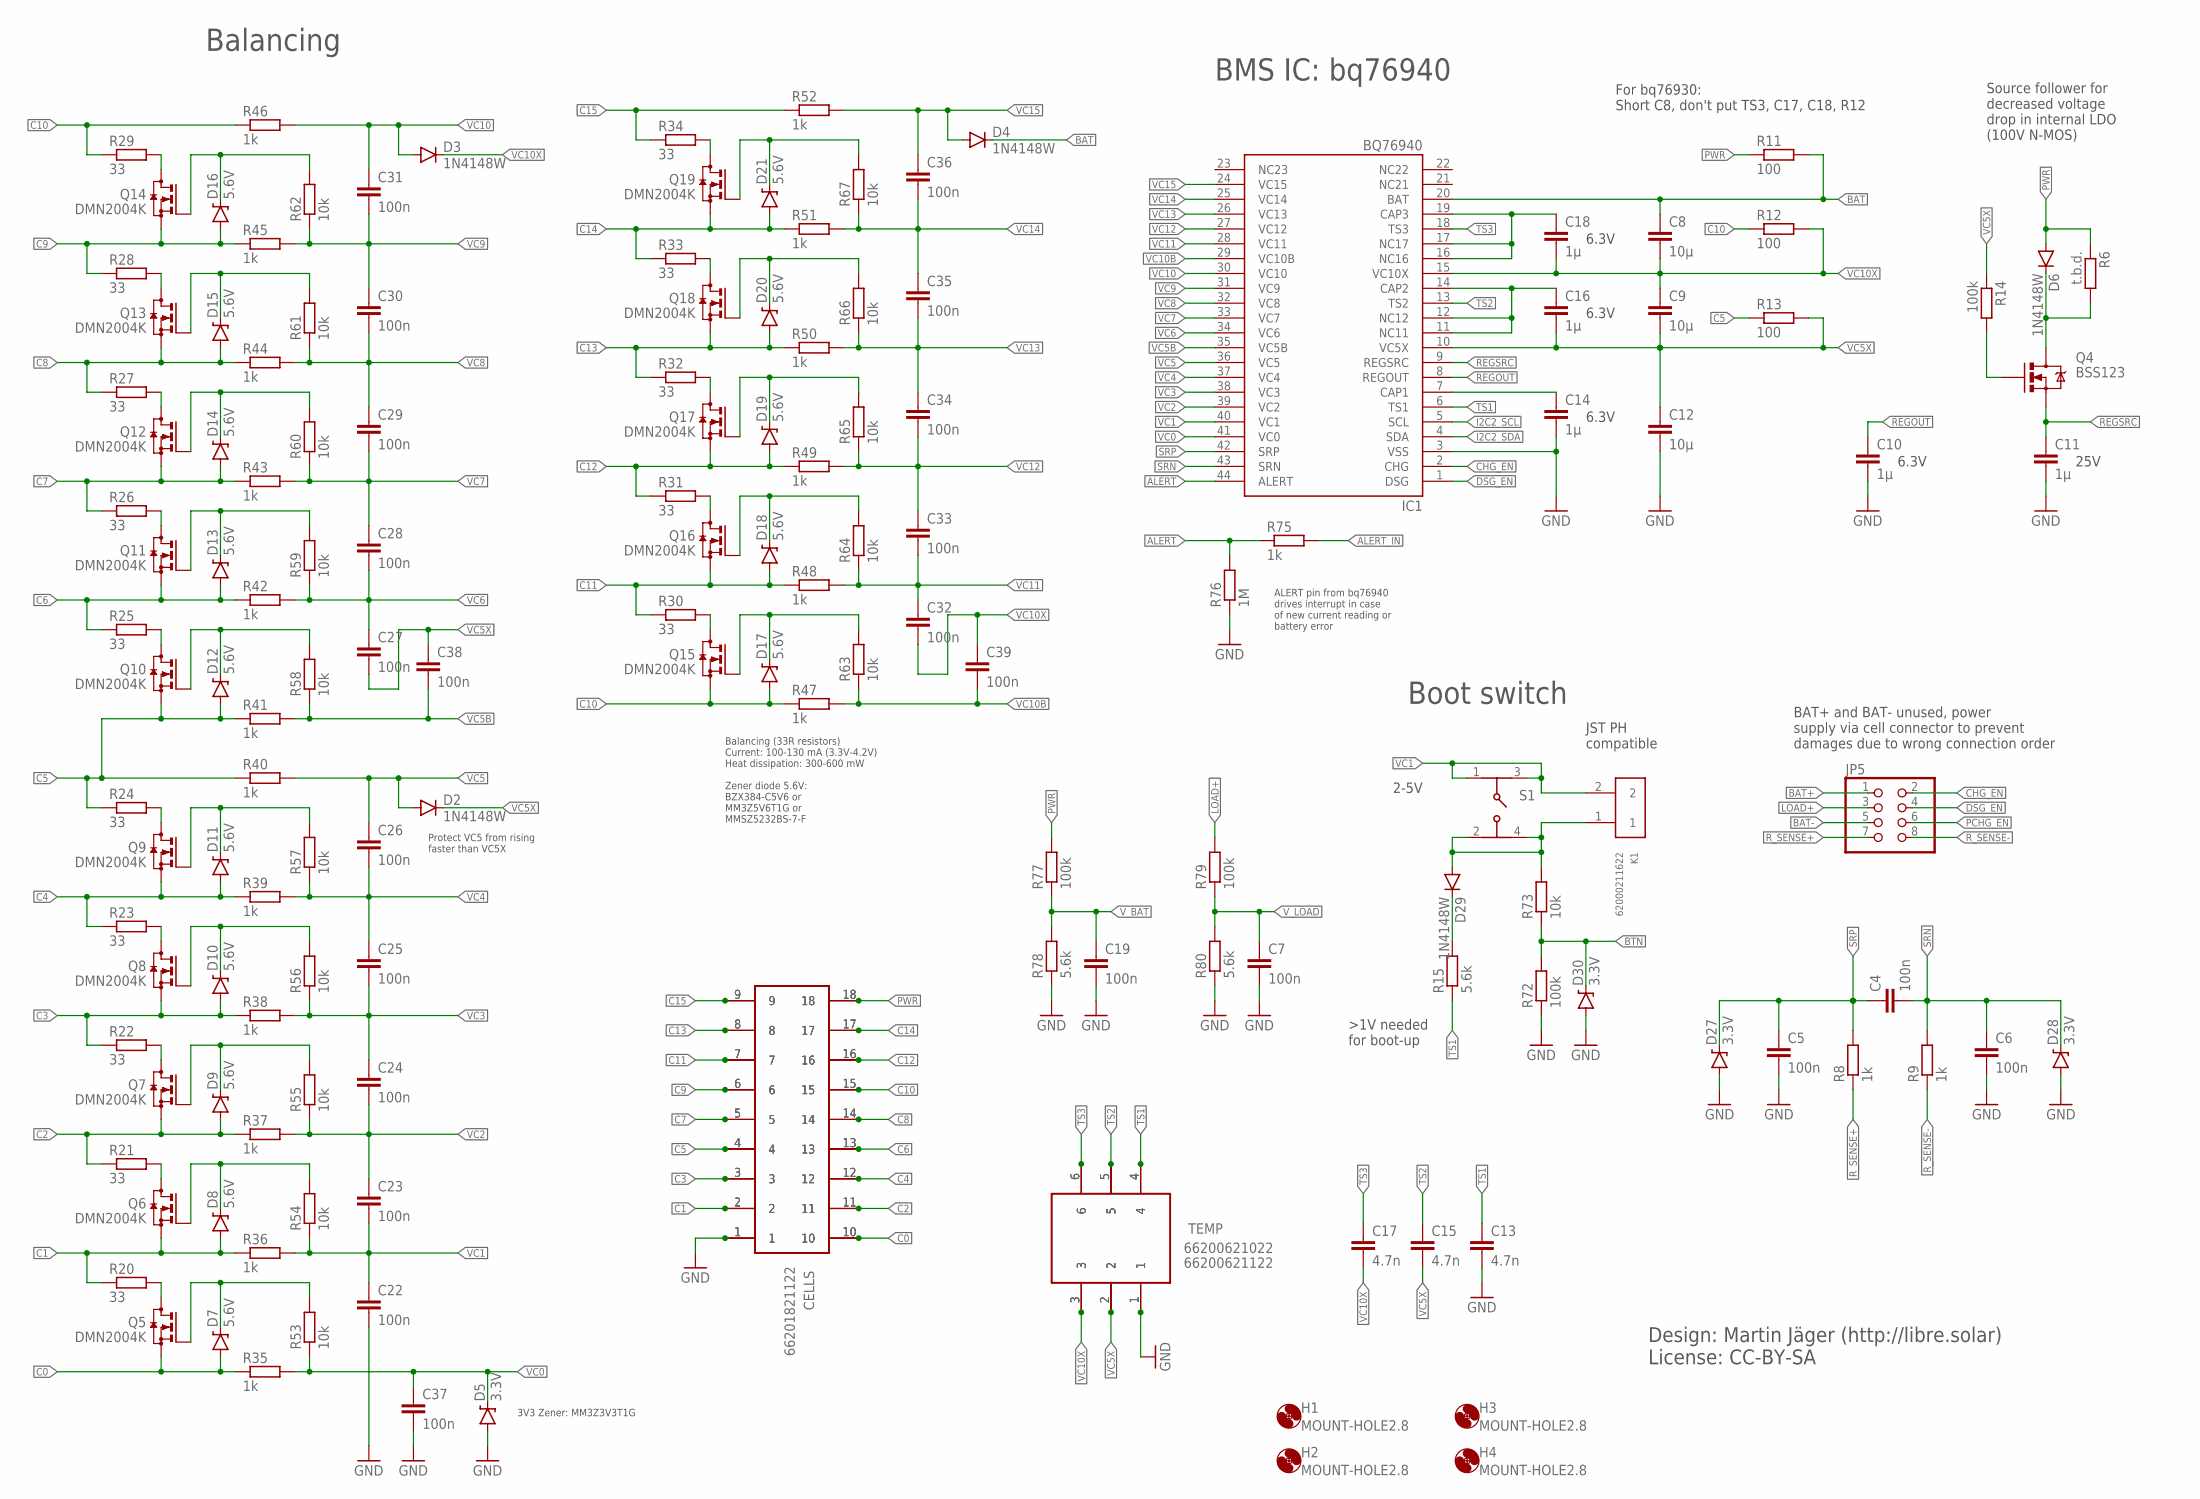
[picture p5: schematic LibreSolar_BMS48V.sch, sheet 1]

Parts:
C4, C5, C6, C7, C19, C22, C23, C24, C25, C26, C27, C28, C29, C30, C31, C32, C33, C34, C35, C36, C37, C38, C39: 100n; C0603; MPN 0603B104K500CT
C8, C9, C12: 10µ; C1210; MPN GRM32ER7YA106KA12L
C10: 1µ; C0603; MPN 0805YC475KAT2A
C11, C14, C16, C18: 1µ; C0603; MPN GRM188R71E105KA12D
C13, C15, C17: 4.7n; C0603; MPN 0603B104K500CT
CELLS: 66201821022
D2, D3, D4, D6, D29: 1N4148W; SOD-123; MPN 1N4148W-7-F.
D5, D27, D28, D30: 3.3V; SOD-323; MPN BZX384-C5V6
D7, D8, D9, D10, D11, D12, D13, D14, D15, D16, D17, D18, D19, D20, D21: 5.6V; SOD-323; MPN BZX384-C5V6
H1, H2, H3, H4: MOUNT-HOLE2.8; 2,8
IC1: BQ76940; TSSOP44; MPN BQ7694003DBT
JP5: PINHD-2X4; 2X04
K1: 62000211622
K4: 66200621122
K5: 66201821122
Q4: BSS123; SOT23-3; MPN 2N7002,215
Q5, Q6, Q7, Q8, Q9, Q10, Q11, Q12, Q13, Q14, Q15, Q16, Q17, Q18, Q19: DMN2004K; SOT23; MPN DMN2004K-7
R6: t.b.d.; R0603; MPN MCMR06X1001FTL
R8, R9, R35, R36, R37, R38, R39, R40, R41, R42, R43, R44, R45, R46, R47, R48, R49, R50, R51, R52, R75: 1k; R0603; MPN MCMR06X1001FTL
R11, R12, R13: 100; R0603; MPN MCMR06X1001FTL
R14: 100k; R0603
R15, R78, R80: 5.6k; R0603; MPN MCMR06X1001FTL
R20, R21, R22, R23, R24, R25, R26, R27, R28, R29, R30, R31, R32, R33, R34: 33; R2010; MPN ASC2010-33RFT4
R53, R54, R55, R56, R57, R58, R59, R60, R61, R62, R63, R64, R65, R66, R67: 10k; R0603; MPN ERJ3EKF1002V
R72, R77, R79: 100k; R0603; MPN MCMR06X1001FTL
R73: 10k; R0603; MPN MCMR06X1001FTL
R76: 1M; R0603; MPN ERJU06F1004V
S1: 430182050816
TEMP: 66200621022

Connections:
ALERT: IC1.44 (ALERT), R75.1, R76.2
ALERT_IN: R75.2; also elsewhere on the board
BAT: C8.1, D4.C, IC1.20 (BAT), R11.2
BAT+: JP5.1
BAT-: JP5.5
BTN: D30.C, R72.2, R73.1; also elsewhere on the board
C0: CELLS.10, D7.A, K5.10, Q5.2 (S), R35.1
C1: CELLS.2, D8.A, K5.2, Q6.2 (S), R20.1, R36.1
C2: CELLS.11, D9.A, K5.11, Q7.2 (S), R21.1, R37.1
C3: CELLS.3, D10.A, K5.3, Q8.2 (S), R22.1, R38.1
C4: CELLS.12, D11.A, K5.12, Q9.2 (S), R23.1, R39.1
C5: CELLS.4, D12.A, K5.4, Q10.2 (S), R13.1, R24.1, R40.1, R41.1
C6: CELLS.13, D13.A, K5.13, Q11.2 (S), R25.1, R42.1
C7: CELLS.5, D14.A, K5.5, Q12.2 (S), R26.1, R43.1
C8: CELLS.14, D15.A, K5.14, Q13.2 (S), R27.1, R44.1
C9: CELLS.6, D16.A, K5.6, Q14.2 (S), R28.1, R45.1
C10: CELLS.15, D17.A, K5.15, Q15.2 (S), R12.1, R29.1, R46.1, R47.1
C11: CELLS.7, D18.A, K5.7, Q16.2 (S), R30.1, R48.1
C12: CELLS.16, D19.A, K5.16, Q17.2 (S), R31.1, R49.1
C13: CELLS.8, D20.A, K5.8, Q18.2 (S), R32.1, R50.1
C14: CELLS.17, D21.A, K5.17, Q19.2 (S), R33.1, R51.1
C15: CELLS.9, K5.9, R34.1, R52.1
CAP1: C14.1, IC1.7 (CAP1)
CAP2: C16.1, IC1.11 (NC11), IC1.12 (NC12), IC1.14 (CAP2)
CAP3: C18.1, IC1.16 (NC16), IC1.17 (NC17), IC1.19 (CAP3)
CHG_EN: IC1.2 (CHG), JP5.2
DSG_EN: IC1.1 (DSG), JP5.4
GND: C5.2, C6.2, C7.2, C10.2, C11.2, C12.2, C13.2, C14.2, C19.2, C22.2, C37.2, CELLS.1, D5.A, D27.A, D28.A, D30.A, IC1.3 (VSS), K4.1, K5.1, R72.1, R76.1, R78.1, R80.1, TEMP.1; also elsewhere on the board
I2C2_SCL: IC1.5 (SCL); also elsewhere on the board
I2C2_SDA: IC1.4 (SDA); also elsewhere on the board
LOAD+: JP5.3, R79.2
MCU_IN: D29.A, K1.1, R73.2, S1.2, S1.4
unnamed: Q15.3 (D), R30.2
unnamed: Q16.3 (D), R31.2
unnamed: Q17.3 (D), R32.2
unnamed: D19.C, Q17.1 (G), R65.2
unnamed: Q6.3 (D), R21.2
unnamed: D18.C, Q16.1 (G), R64.2
unnamed: D7.C, Q5.1 (G), R53.2
unnamed: D29.C, R15.2
unnamed: D8.C, Q6.1 (G), R54.2
unnamed: D9.C, Q7.1 (G), R55.2
unnamed: Q5.3 (D), R20.2
unnamed: Q7.3 (D), R22.2
unnamed: D10.C, Q8.1 (G), R56.2
unnamed: Q8.3 (D), R23.2
unnamed: Q9.3 (D), R24.2
unnamed: D11.C, Q9.1 (G), R57.2
unnamed: D12.C, Q10.1 (G), R58.2
unnamed: Q10.3 (D), R25.2
unnamed: Q11.3 (D), R26.2
unnamed: D13.C, Q11.1 (G), R59.2
unnamed: D14.C, Q12.1 (G), R60.2
unnamed: Q12.3 (D), R27.2
unnamed: D15.C, Q13.1 (G), R61.2
unnamed: Q13.3 (D), R28.2
unnamed: Q14.3 (D), R29.2
unnamed: D16.C, Q14.1 (G), R62.2
unnamed: D17.C, Q15.1 (G), R63.2
unnamed: D20.C, Q18.1 (G), R66.2
unnamed: Q18.3 (D), R33.2
unnamed: D21.C, Q19.1 (G), R67.2
unnamed: Q19.3 (D), R34.2
unnamed: D6.C, Q4.3 (D), R6.2
unnamed: Q4.1 (G), R14.2
PCHG_EN: JP5.6; also elsewhere on the board
PWR: CELLS.18, D6.A, K5.18, R6.1, R11.1, R77.2; also elsewhere on the board
REGOUT: C10.1, IC1.8 (REGOUT); also elsewhere on the board
REGSRC: C11.1, IC1.9 (REGSRC), Q4.2 (S)
R_SENSE+: JP5.7, R8.1
R_SENSE-: JP5.8, R9.1
SRN: C4.2, C6.1, D28.C, IC1.43 (SRN), R9.2
SRP: C4.1, C5.1, D27.C, IC1.42 (SRP), R8.2
TS1: C13.1, IC1.6 (TS1), K4.4, R15.1, TEMP.4; also elsewhere on the board
TS2: C15.1, IC1.13 (TS2), K4.5, TEMP.5
TS3: C17.1, IC1.18 (TS3), K4.6, TEMP.6
VC0: C37.1, D5.C, IC1.41 (VC0), R35.2, R53.1
VC1: C22.1, C23.2, IC1.40 (VC1), K1.2, R36.2, R54.1, S1.1, S1.3
VC2: C23.1, C24.2, IC1.39 (VC2), R37.2, R55.1
VC3: C24.1, C25.2, IC1.38 (VC3), R38.2, R56.1
VC4: C25.1, C26.2, IC1.37 (VC4), R39.2, R57.1
VC5: C26.1, D2.A, IC1.36 (VC5), R40.2
VC5B: C38.2, IC1.35 (VC5B), R41.2, R58.1
VC5X: C9.2, C12.1, C15.2, C16.2, C27.2, C38.1, D2.C, IC1.10 (VC5X), K4.2, R13.2, R14.1, TEMP.2
VC6: C27.1, C28.2, IC1.34 (VC6), R42.2, R59.1
VC7: C28.1, C29.2, IC1.33 (VC7), R43.2, R60.1
VC8: C29.1, C30.2, IC1.32 (VC8), R44.2, R61.1
VC9: C30.1, C31.2, IC1.31 (VC9), R45.2, R62.1
VC10: C31.1, D3.A, IC1.30 (VC10), R46.2
VC10B: C39.2, IC1.29 (VC10B), R47.2, R63.1
VC10X: C8.2, C9.1, C17.2, C18.2, C32.2, C39.1, D3.C, IC1.15 (VC10X), K4.3, R12.2, TEMP.3
VC11: C32.1, C33.2, IC1.28 (VC11), R48.2, R64.1
VC12: C33.1, C34.2, IC1.27 (VC12), R49.2, R65.1
VC13: C34.1, C35.2, IC1.26 (VC13), R50.2, R66.1
VC14: C35.1, C36.2, IC1.25 (VC14), R51.2, R67.1
VC15: C36.1, D4.A, IC1.24 (VC15), R52.2
V_BAT: C19.1, R77.1, R78.2; also elsewhere on the board
V_LOAD: C7.1, R79.1, R80.2; also elsewhere on the board

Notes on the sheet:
Balancing (33R resistors) Current: 100-130 mA (3.3V-4.2V) Heat dissipation: 300-600 mW Zener diode 5.6V: BZX384-C5V6 or MM3Z5V6T1G or MMSZ5232BS-7-F
Balancing
BMS IC: bq76940
Design: Martin Jäger (http://libre.solar) License: CC-BY-SA
25V
6.3V
For bq76930: Short C8, don't put TS3, C17, C18, R12
Protect VC5 from rising faster than VC5X
Source follower for decreased voltage drop in internal LDO (100V N-MOS)
3V3 Zener: MM3Z3V3T1G
ALERT pin from bq76940 drives interrupt in case of new current reading or battery error
2-5V
BAT+ and BAT- unused, power supply via cell connector to prevent damages due to wrong connection order
Boot switch
JST PH compatible

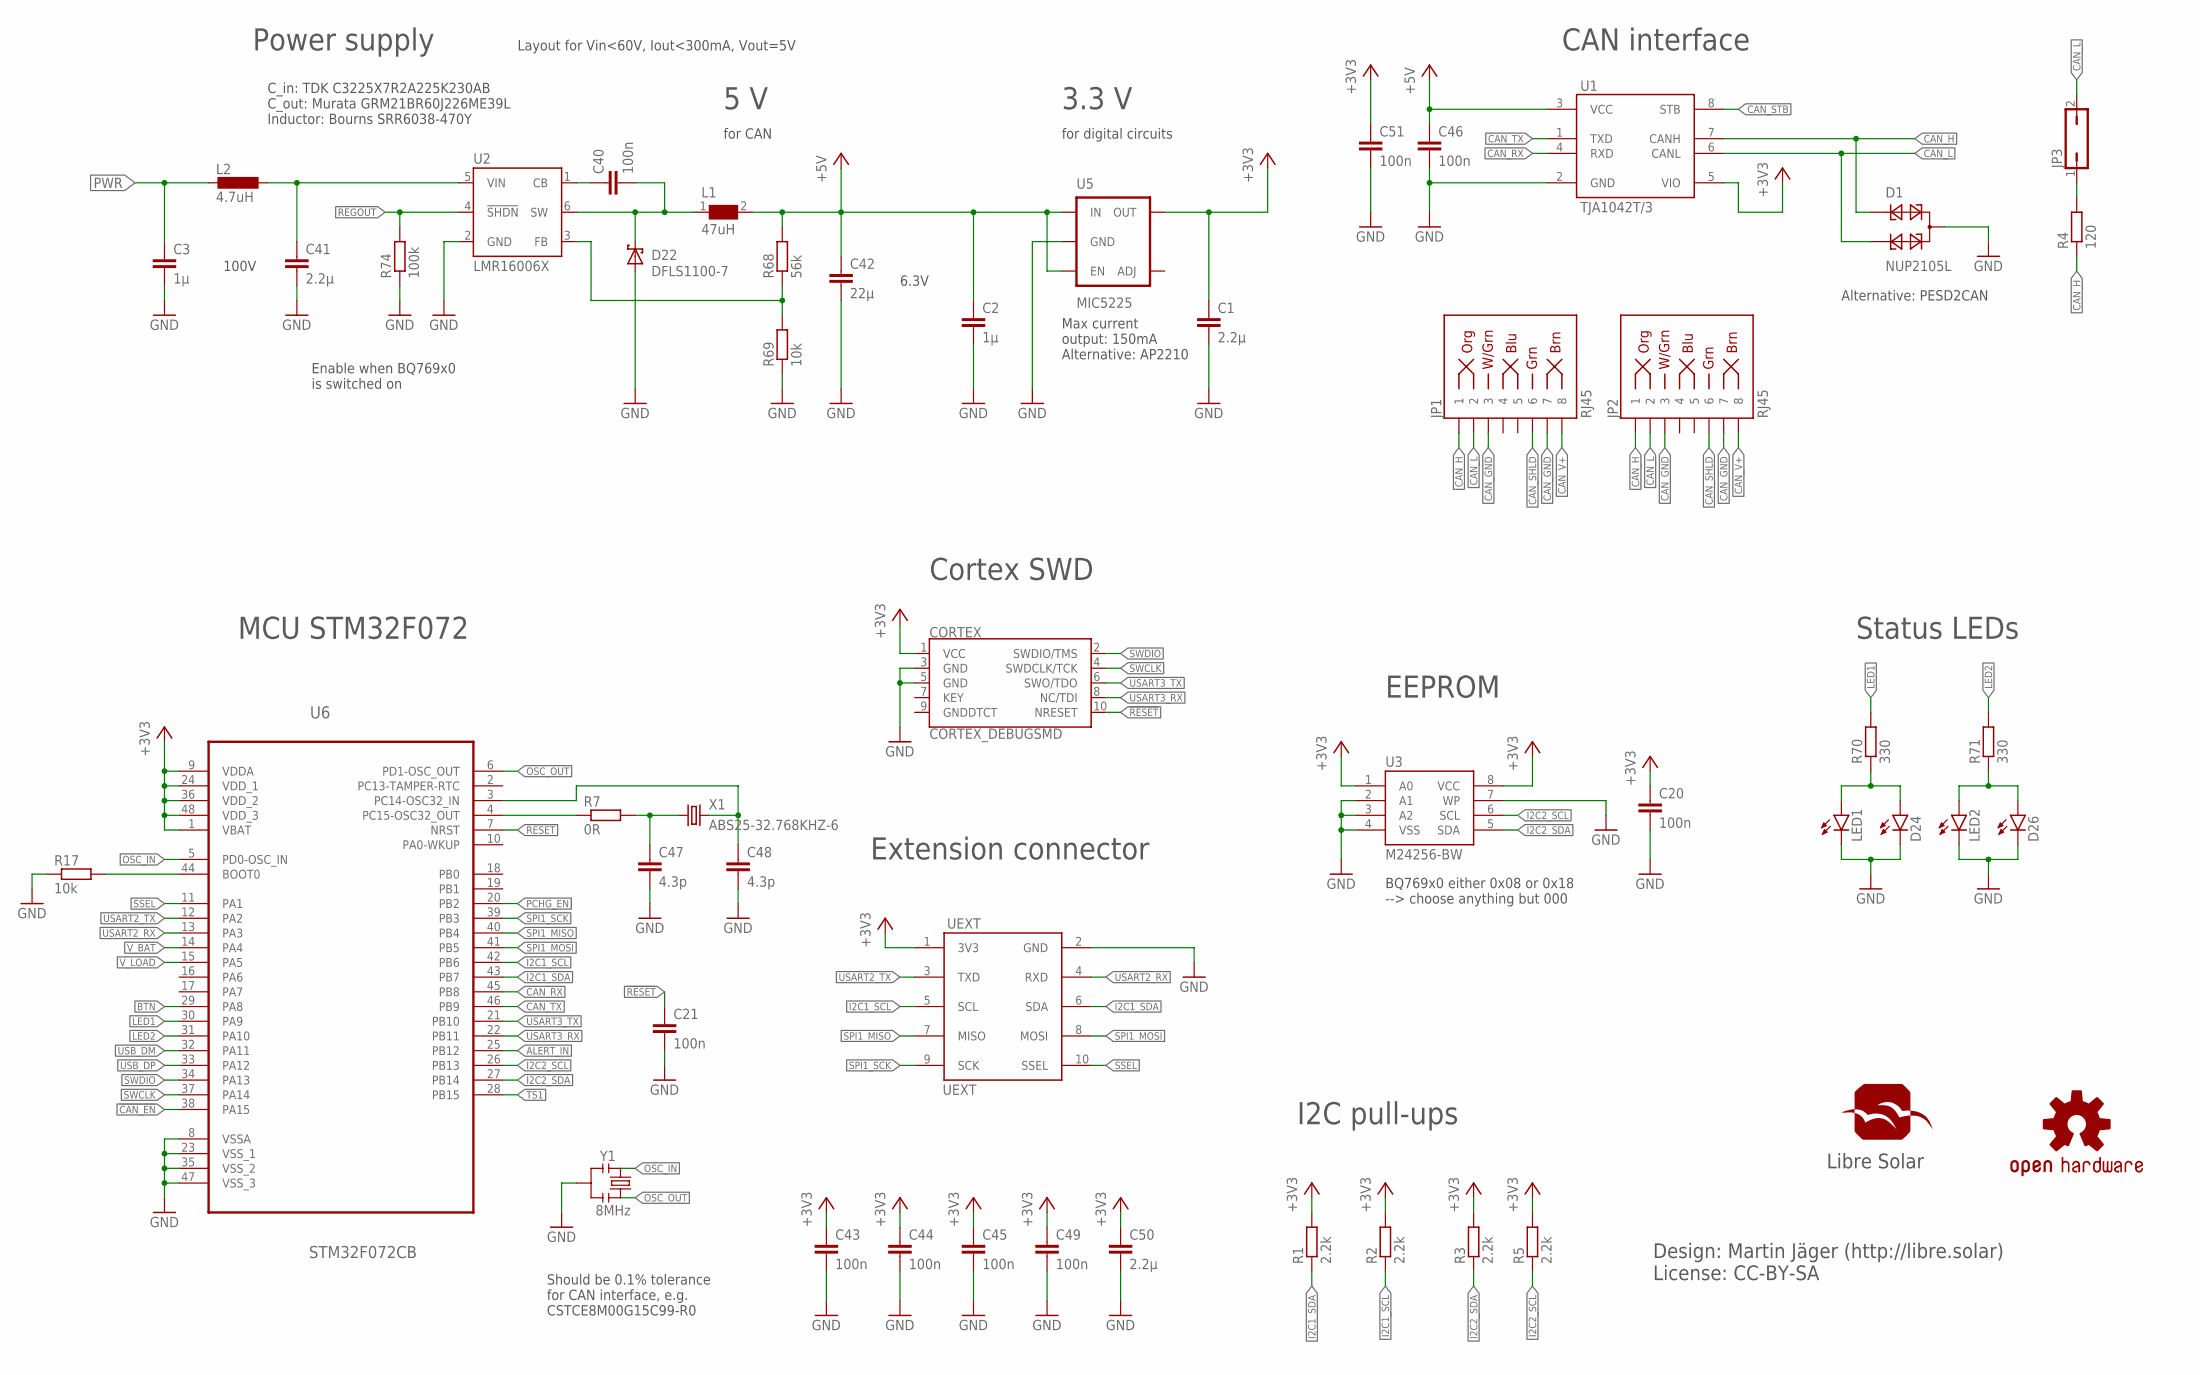
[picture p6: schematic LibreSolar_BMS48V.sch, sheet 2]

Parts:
C1, C50: 2.2µ; C0603; MPN 0805YC475KAT2A
C2: 1µ; C0603; MPN 08055C104KAT2A
C3: 1µ; C0805; MPN 08055C104KAT2A
C20, C21, C43, C44, C45, C49: 100n; C0603; MPN GRM188R71H104KA93D
C40: 100n; C0603; MPN 0603B104K500CT
C41: 2.2µ; C1210; MPN C3225X7R2A225K230AB
C42: 22µ; C0805; MPN GRM21BR60J226ME39L
C46, C51: 100n; C0603; MPN 06035C104KAT2A
C47, C48: 4.3p; C0603; MPN GRM188R71H104KA93D
CORTEX: CORTEX_DEBUGSMD; SAMTECH_FTSH-105-01
D1: NUP2105L; SOT23; MPN PESD2CAN
D22: DFLS1100-7; POWERDI123; MPN DFLS1100-7
D24, D26: LED0603; LED-0603
JP1, JP2: RJ45; RJ45-8; MPN RJHSE-5080
JP3: JP1Q; JP1
L1: 47uH; WE-TPC_6823
L2: 4.7uH; L2012C
LED1, LED2: LED3MM
N1: OSHW-LOGOM; OSHW-LOGO-M
R1, R2, R3, R5: 2.2k; R0603; MPN RC0603FR-072K2L.
R4: 120; R1206; MPN WCR0805-120RFI
R7: 0R; R0603; MPN RC0603FR-0710KL
R17: 10k; R0603; MPN RC0603FR-0710KL
R68: 56k; R0603; MPN CR0805-FX-1001ELF
R69: 10k; R0603; MPN ERJ3EKF1002V
R70, R71: 330; R0603; MPN MCMR06X1001FTL
R74: 100k; R0603; MPN ERJ3EKF1002V
U1: TJA1042T/3; SOIC-8-N
U2: LMR16006X; SOT23-6; MPN LMR16006XDDCT
U3: M24256-BW; SO08
U5: MIC5225; SOT23-5; MPN MIC5225-3.3YM5-TR
U6: STM32F072CB; QFP50P900X900X160-48N
U$1: LIBRESOLAR_LOGO
UEXT: UEXT
X1: ABS25-32.768KHZ-6; MM20SS
Y1: 8MHz; RESONATOR-SMD-1:1; MPN CSTCE8M00G15C99-R0

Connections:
!CAN_EN!: U6.38 (PA15)
!RESET: C21.1, CORTEX.10 (NRESET), U6.7 (NRST)
+3V3: C1.1, C20.1, C43.1, C44.1, C45.1, C49.1, C50.1, C51.1, CORTEX.1 (VCC), R1.2, R2.2, R3.2, R5.2, U1.5 (VIO), U3.1 (A0), U3.8 (VCC), U5.5 (OUT), U6.1 (VBAT), U6.9 (VDDA), U6.24 (VDD_1), U6.36 (VDD_2), U6.48 (VDD_3), UEXT.1 (3V3)
+5V: C2.1, C42.1, C46.1, L1.2, R68.2, U1.3 (VCC), U5.1 (IN), U5.3 (EN)
ALERT_IN: U6.25 (PB12); also elsewhere on the board
BTN: U6.29 (PA8); also elsewhere on the board
CAN_GND: JP1.3, JP1.7, JP2.3, JP2.7
CAN_H: D1.1, JP1.1, JP2.1, R4.1, U1.7 (CANH)
CAN_L: D1.2, JP1.2, JP2.2, JP3.2, U1.6 (CANL)
CAN_RX: U1.4 (RXD), U6.45 (PB8)
CAN_SHLD: JP1.6, JP2.6
CAN_STB: U1.8 (STB)
CAN_TX: U1.1 (TXD), U6.46 (PB9)
CAN_V+: JP1.8, JP2.8
GND: C1.2, C2.2, C3.2, C20.2, C21.2, C41.2, C42.2, C43.2, C44.2, C45.2, C46.2, C47.2, C48.2, C49.2, C50.2, C51.2, CORTEX.3 (GND), CORTEX.5 (GND), D1.3, D22.A, D24.C, D26.C, LED1.K (C), LED2.K (C), R17.1, R69.1, R74.1, U1.2 (GND), U2.2 (GND), U3.2 (A1), U3.3 (A2), U3.4 (VSS), U3.7 (WP), U5.2 (GND), U6.8 (VSSA), U6.23 (VSS_1), U6.35 (VSS_2), U6.47 (VSS_3), UEXT.2 (GND), Y1.2; also elsewhere on the board
I2C1_SCL: R2.1, U6.42 (PB6), UEXT.5 (SCL)
I2C1_SDA: R1.1, U6.43 (PB7), UEXT.6 (SDA)
I2C2_SCL: R5.1, U3.6 (SCL), U6.26 (PB13); also elsewhere on the board
I2C2_SDA: R3.1, U3.5 (SDA), U6.27 (PB14); also elsewhere on the board
LED1: R70.2, U6.30 (PA9)
LED2: R71.2, U6.31 (PA10)
unnamed: C41.1, L2.1, U2.5 (VIN)
unnamed: R68.1, R69.2, U2.3 (FB)
unnamed: C40.2, D22.C, L1.1, U2.6 (SW)
unnamed: C40.1, U2.1 (CB)
unnamed: JP3.1, R4.2
unnamed: R7.1, U6.4 (PC15-OSC32_OUT)
unnamed: C47.1, R7.2, X1.1
unnamed: D24.A, LED1.A, R70.1
unnamed: C48.1, U6.3 (PC14-OSC32_IN), X1.4 (2)
unnamed: D26.A, LED2.A, R71.1
unnamed: R17.2, U6.44 (BOOT0)
OSC_IN: U6.5 (PD0-OSC_IN), Y1.1
OSC_OUT: U6.6 (PD1-OSC_OUT), Y1.3
PCHG_EN: U6.20 (PB2); also elsewhere on the board
PWR: C3.1, L2.2; also elsewhere on the board
REGOUT: R74.2, U2.4 (!SHDN!); also elsewhere on the board
SPI1_MISO: U6.40 (PB4), UEXT.7 (MISO)
SPI1_MOSI: U6.41 (PB5), UEXT.8 (MOSI)
SPI1_SCK: U6.39 (PB3), UEXT.9 (SCK)
SSEL: U6.11 (PA1), UEXT.10 (SSEL)
SWCLK: CORTEX.4 (SWDCLK/TCK), U6.37 (PA14)
SWDIO: CORTEX.2 (SWDIO/TMS), U6.34 (PA13)
TS1: U6.28 (PB15); also elsewhere on the board
USART2_RX: U6.13 (PA3), UEXT.4 (RXD)
USART2_TX: U6.12 (PA2), UEXT.3 (TXD)
USART3_RX: CORTEX.8 (NC/TDI), U6.22 (PB11)
USART3_TX: CORTEX.6 (SWO/TDO), U6.21 (PB10)
USB_DM: U6.32 (PA11)
USB_DP: U6.33 (PA12)
V_BAT: U6.14 (PA4); also elsewhere on the board
V_LOAD: U6.15 (PA5); also elsewhere on the board

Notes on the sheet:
C_in: TDK C3225X7R2A225K230AB C_out: Murata GRM21BR60J226ME39L Inductor: Bourns SRR6038-470Y
Layout for Vin<60V, Iout<300mA, Vout=5V
100V
6.3V
Power supply
Status LEDs
Design: Martin Jäger (http://libre.solar) License: CC-BY-SA
MCU STM32F072
Extension connector
CAN interface
I2C pull-ups
Alternative: PESD2CAN
Should be 0.1% tolerance for CAN interface, e.g. CSTCE8M00G15C99-R0
Cortex SWD
Max current output: 150mA Alternative: AP2210
3.3 V
for digital circuits
5 V
for CAN
Enable when BQ769x0 is switched on
BQ769x0 either 0x08 or 0x18 --> choose anything but 000
EEPROM

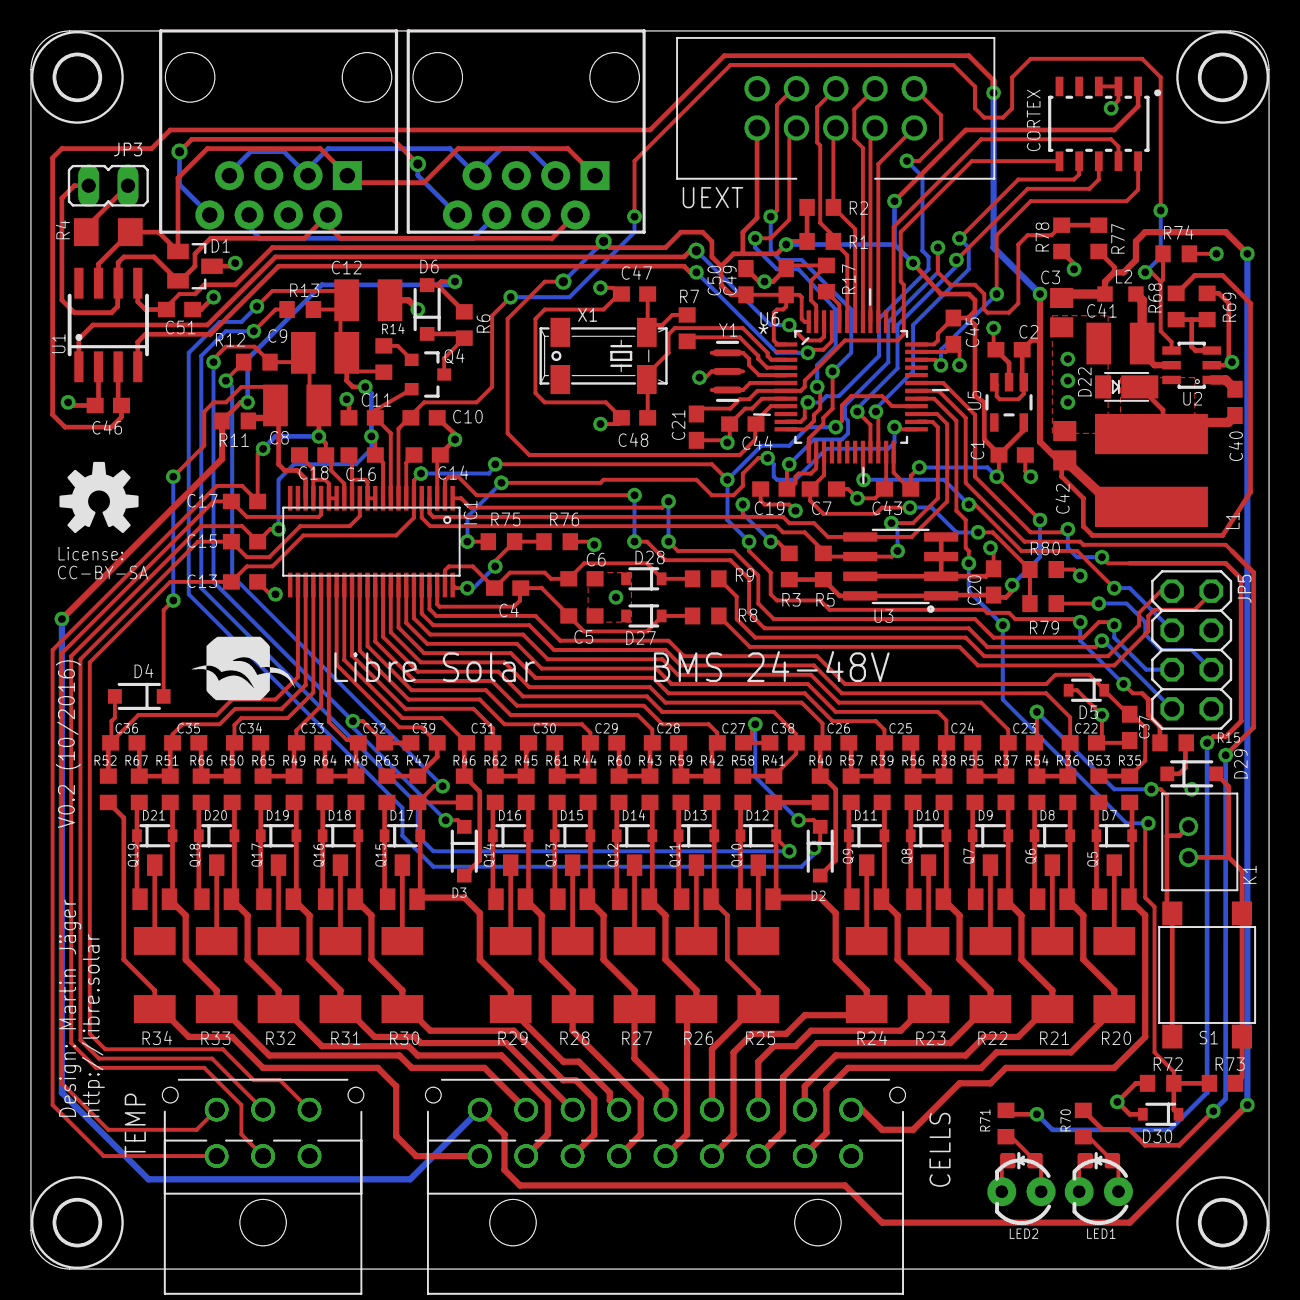
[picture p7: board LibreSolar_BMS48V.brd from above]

Board: 8 copper layers, 80.0 x 80.0 mm, 201 parts (0 on the bottom side), 133 nets.

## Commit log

2016-03-05 Initial checkin of first board files
    [LibreSolar_BMS48V.brd, LibreSolar_BMS48V.sch]
2016-03-25 Pinout of extension connector (LSX) changed
    [LibreSolar_BMS48V.brd, LibreSolar_BMS48V.sch]
2016-10-03 Complete redesign with STM32F072 and external power part
    [LibreSolar_BMS48V.brd, LibreSolar_BMS48V.sch]
2016-12-17 Uploaded image of assembled PCB
    [LibreSolar_BMS48V.brd, LibreSolar_BMS48V.csv, LibreSolar_BMS48V.sch]

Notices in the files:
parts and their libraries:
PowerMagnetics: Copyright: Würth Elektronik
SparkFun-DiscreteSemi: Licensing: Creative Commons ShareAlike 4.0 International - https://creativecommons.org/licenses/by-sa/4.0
